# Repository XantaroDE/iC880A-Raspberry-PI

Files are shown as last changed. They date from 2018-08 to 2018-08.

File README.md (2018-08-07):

# Raspberry PI + IMST iC880A Gateway Shield

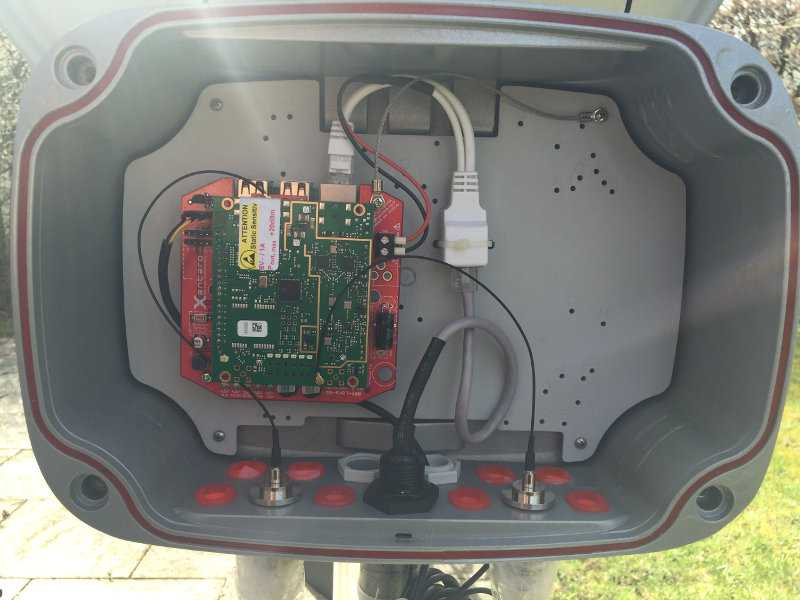
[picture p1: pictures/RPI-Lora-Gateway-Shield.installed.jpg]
Installed
   

Based on the idea of [ch2i][1], but complete rework.

This PCB is used to connect Raspberry PI and ISMT [iC880A][2] LoraWan concentrator Gateway (SPI version) togehter and to be able to put the whole thing into a outdoor enclosure. Power can be supplied via passive or active PoE adapters.

:warning: **Use at your own risk, always check your layout before manufacturing!**

## Features

 - highvoltage power regulator for passive PoE -48V usage based on LM2576
 - optional use DC/DC module for active PoE adapters with +12V output
 - BME280 header for temperature & humidity measurement within the housing, optional BMP280
 - DS18S20 Header for outside & inside/case sensor
 - added GPS module for time & PPS sync
 - optional +3V3 -> +5V TTL serial converter, could be used for other sensors like [SDS011][3] dust particle sensor 
 - LC filters on power supply rails
 - LED for GPS PPS and signal routed to GPIO25
 - DS1307 RTC hardware clock for Raspberry + Battery 

## Schematic

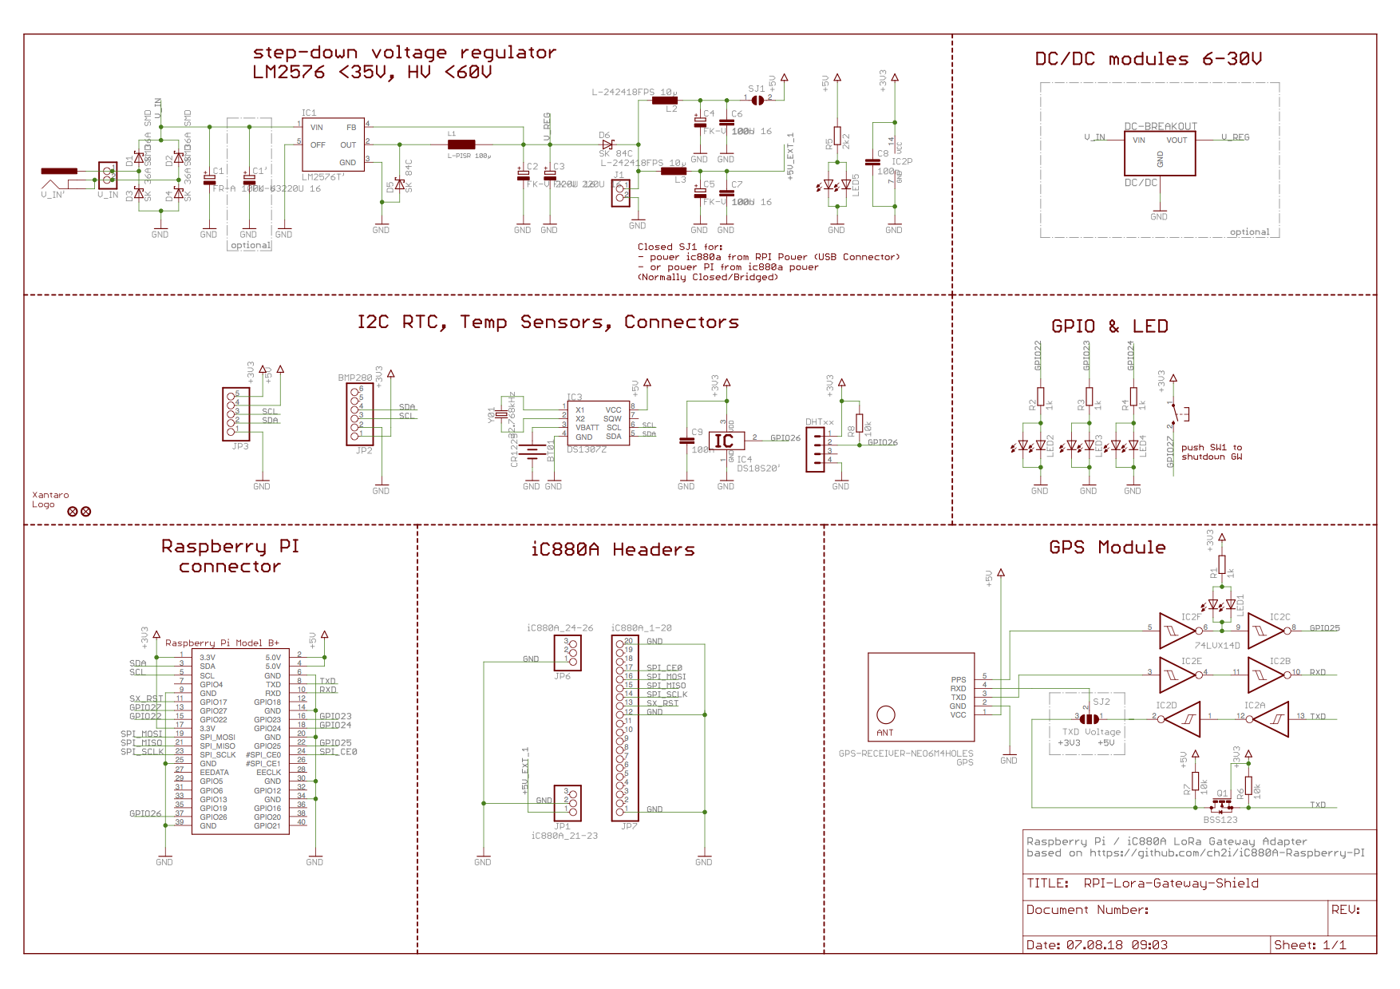
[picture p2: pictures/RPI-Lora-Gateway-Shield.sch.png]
schematic
<br>
[PDF download](https://raw.githubusercontent.com/XantaroDE/iC880A-Raspberry-PI/master/pictures/RPI-Lora-Gateway-Shield.sch.pdf)

## Board

**Top side**

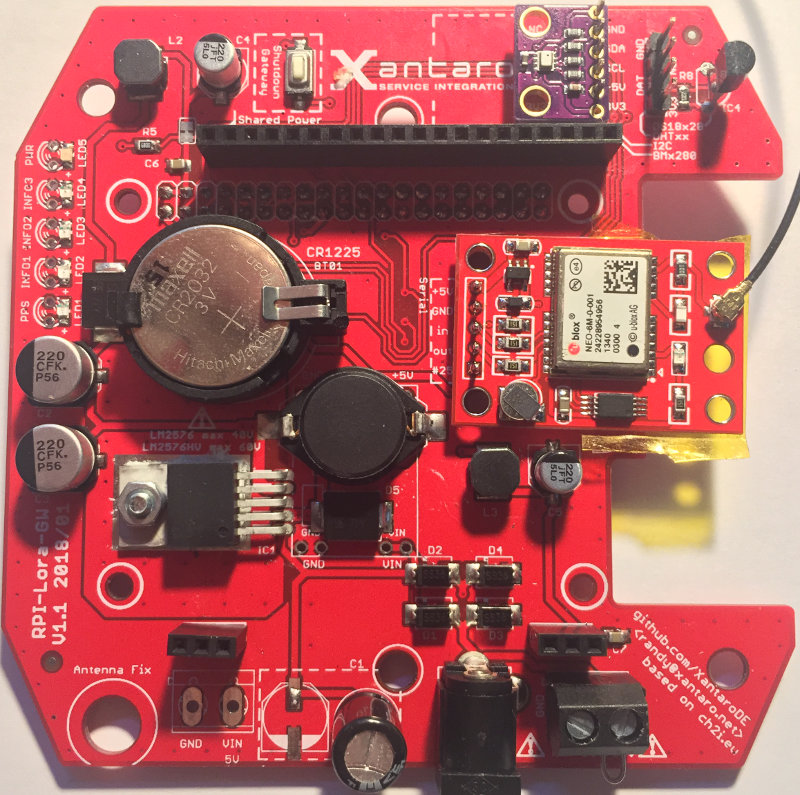
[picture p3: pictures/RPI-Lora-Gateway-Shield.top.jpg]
PCB TOP
    

**Bottom side**

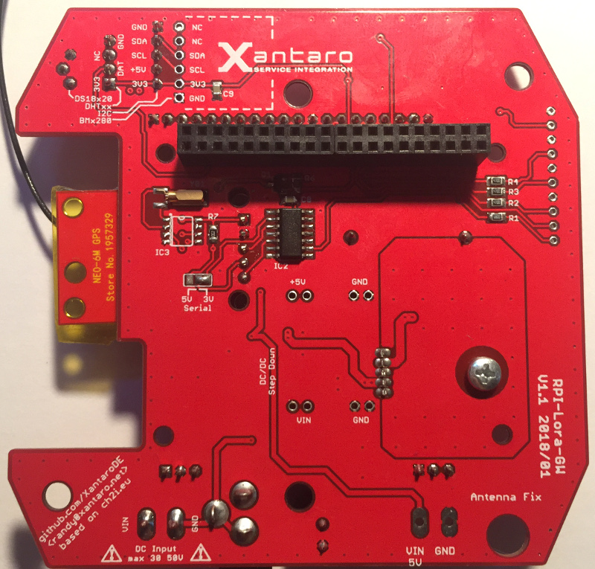
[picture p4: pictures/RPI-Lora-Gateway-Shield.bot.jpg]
PCB BOT
    

You can order the PCB of this board at [elecrow][4] with the supplied gerbers.

## License

   

This work is licensed under a [Creative Commons Attribution-NonCommercial 4.0 International License](http://creativecommons.org/licenses/by-nc/4.0/)    
If you want to do commercial stuff with this project, please contact [Xantaro Deutschland GmbH](https://www.xantaro.net) so we can organize an simple agreement.

[1]: https://github.com/ch2i/iC880A-Raspberry-PI/
[2]: http://webshop.imst.de/ic880a-spi-lorawan-concentrator-868mhz.html
[3]: https://luftdaten.info/
[4]: https://www.elecrow.com/pcb-manufacturing.html

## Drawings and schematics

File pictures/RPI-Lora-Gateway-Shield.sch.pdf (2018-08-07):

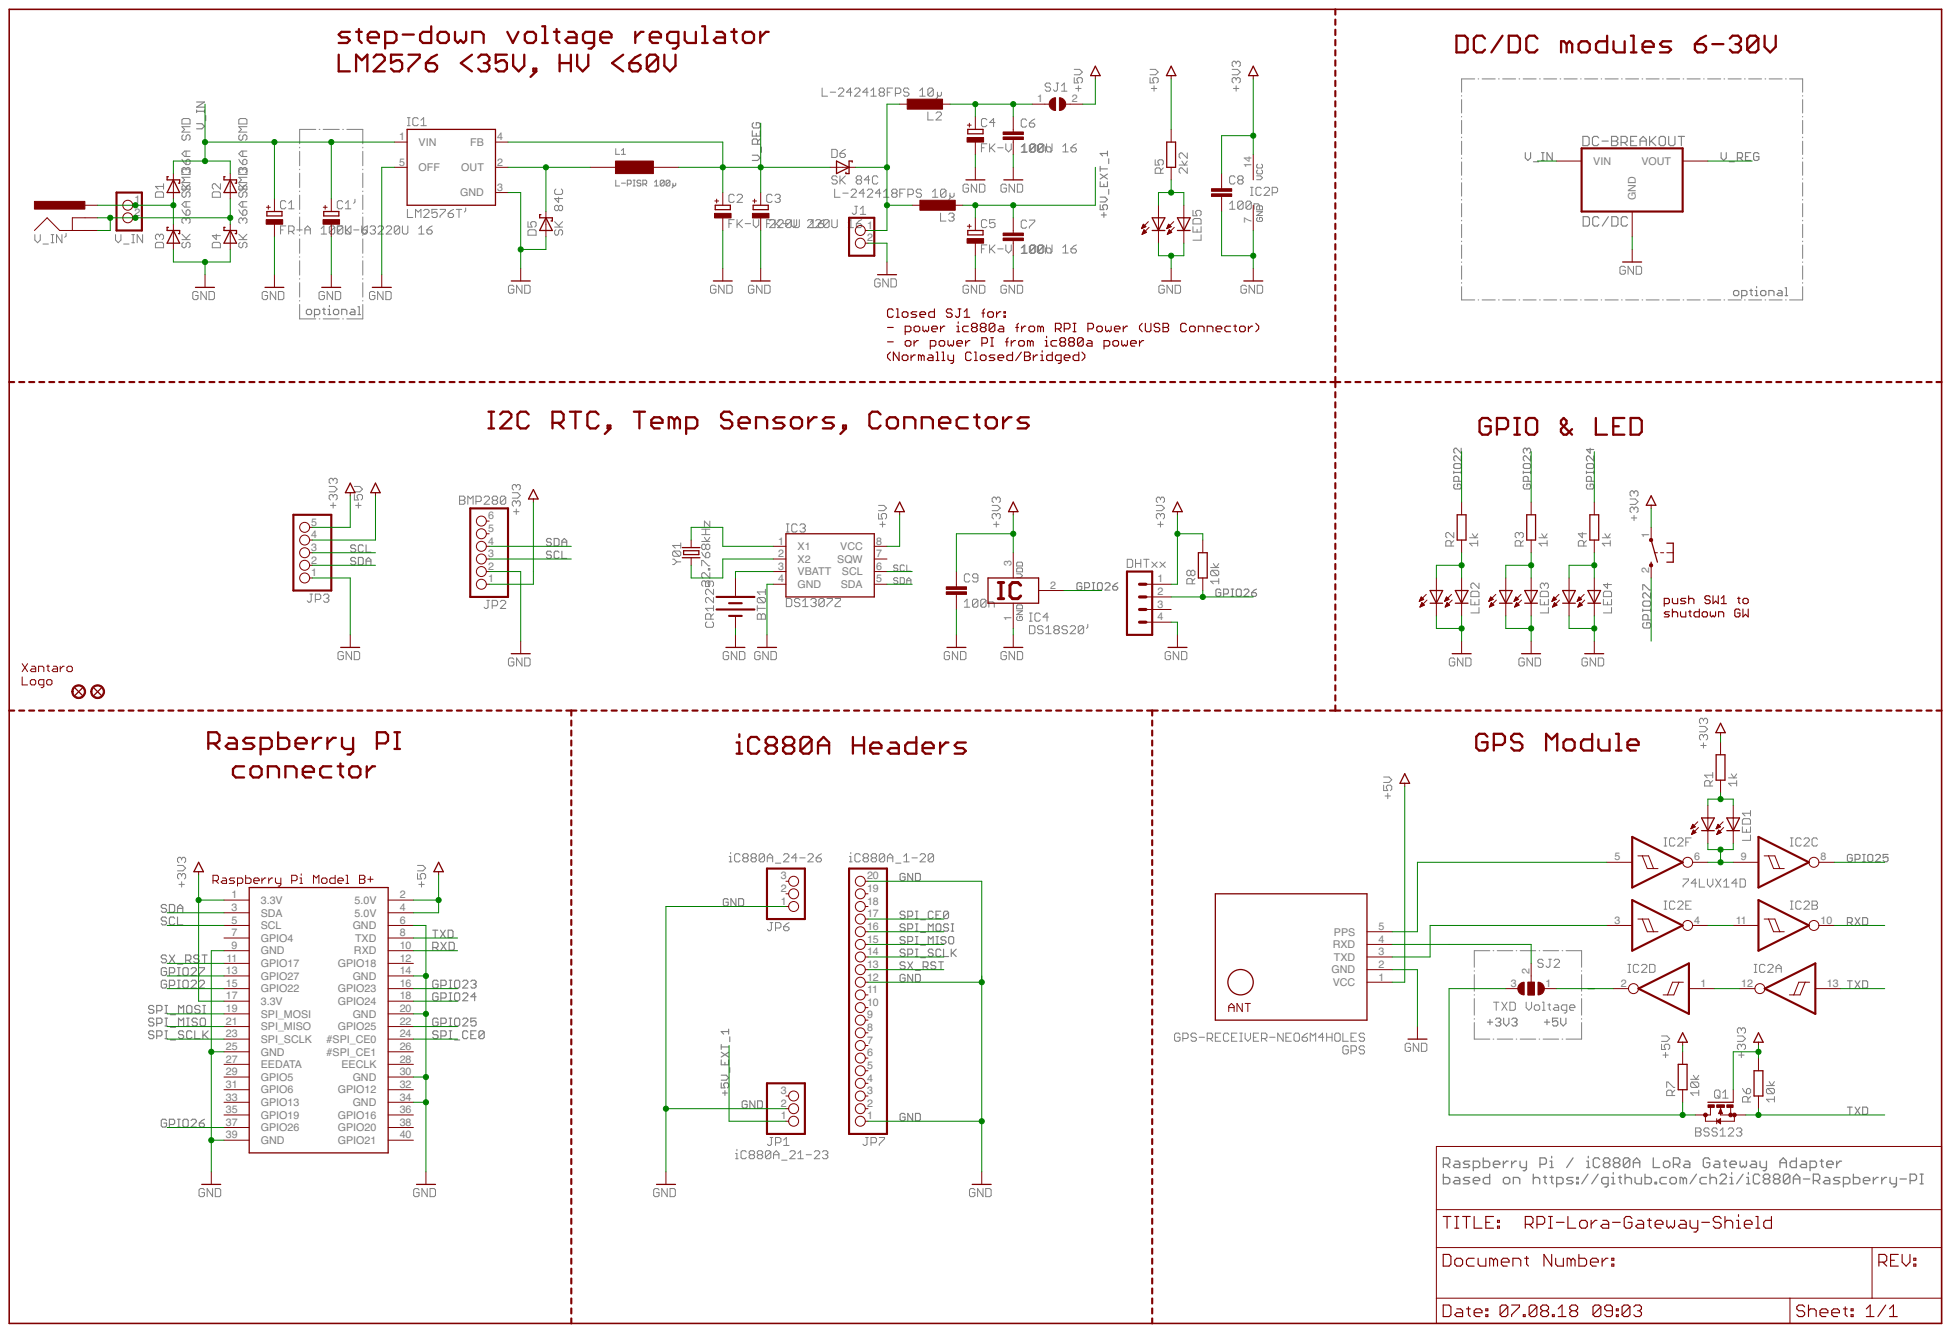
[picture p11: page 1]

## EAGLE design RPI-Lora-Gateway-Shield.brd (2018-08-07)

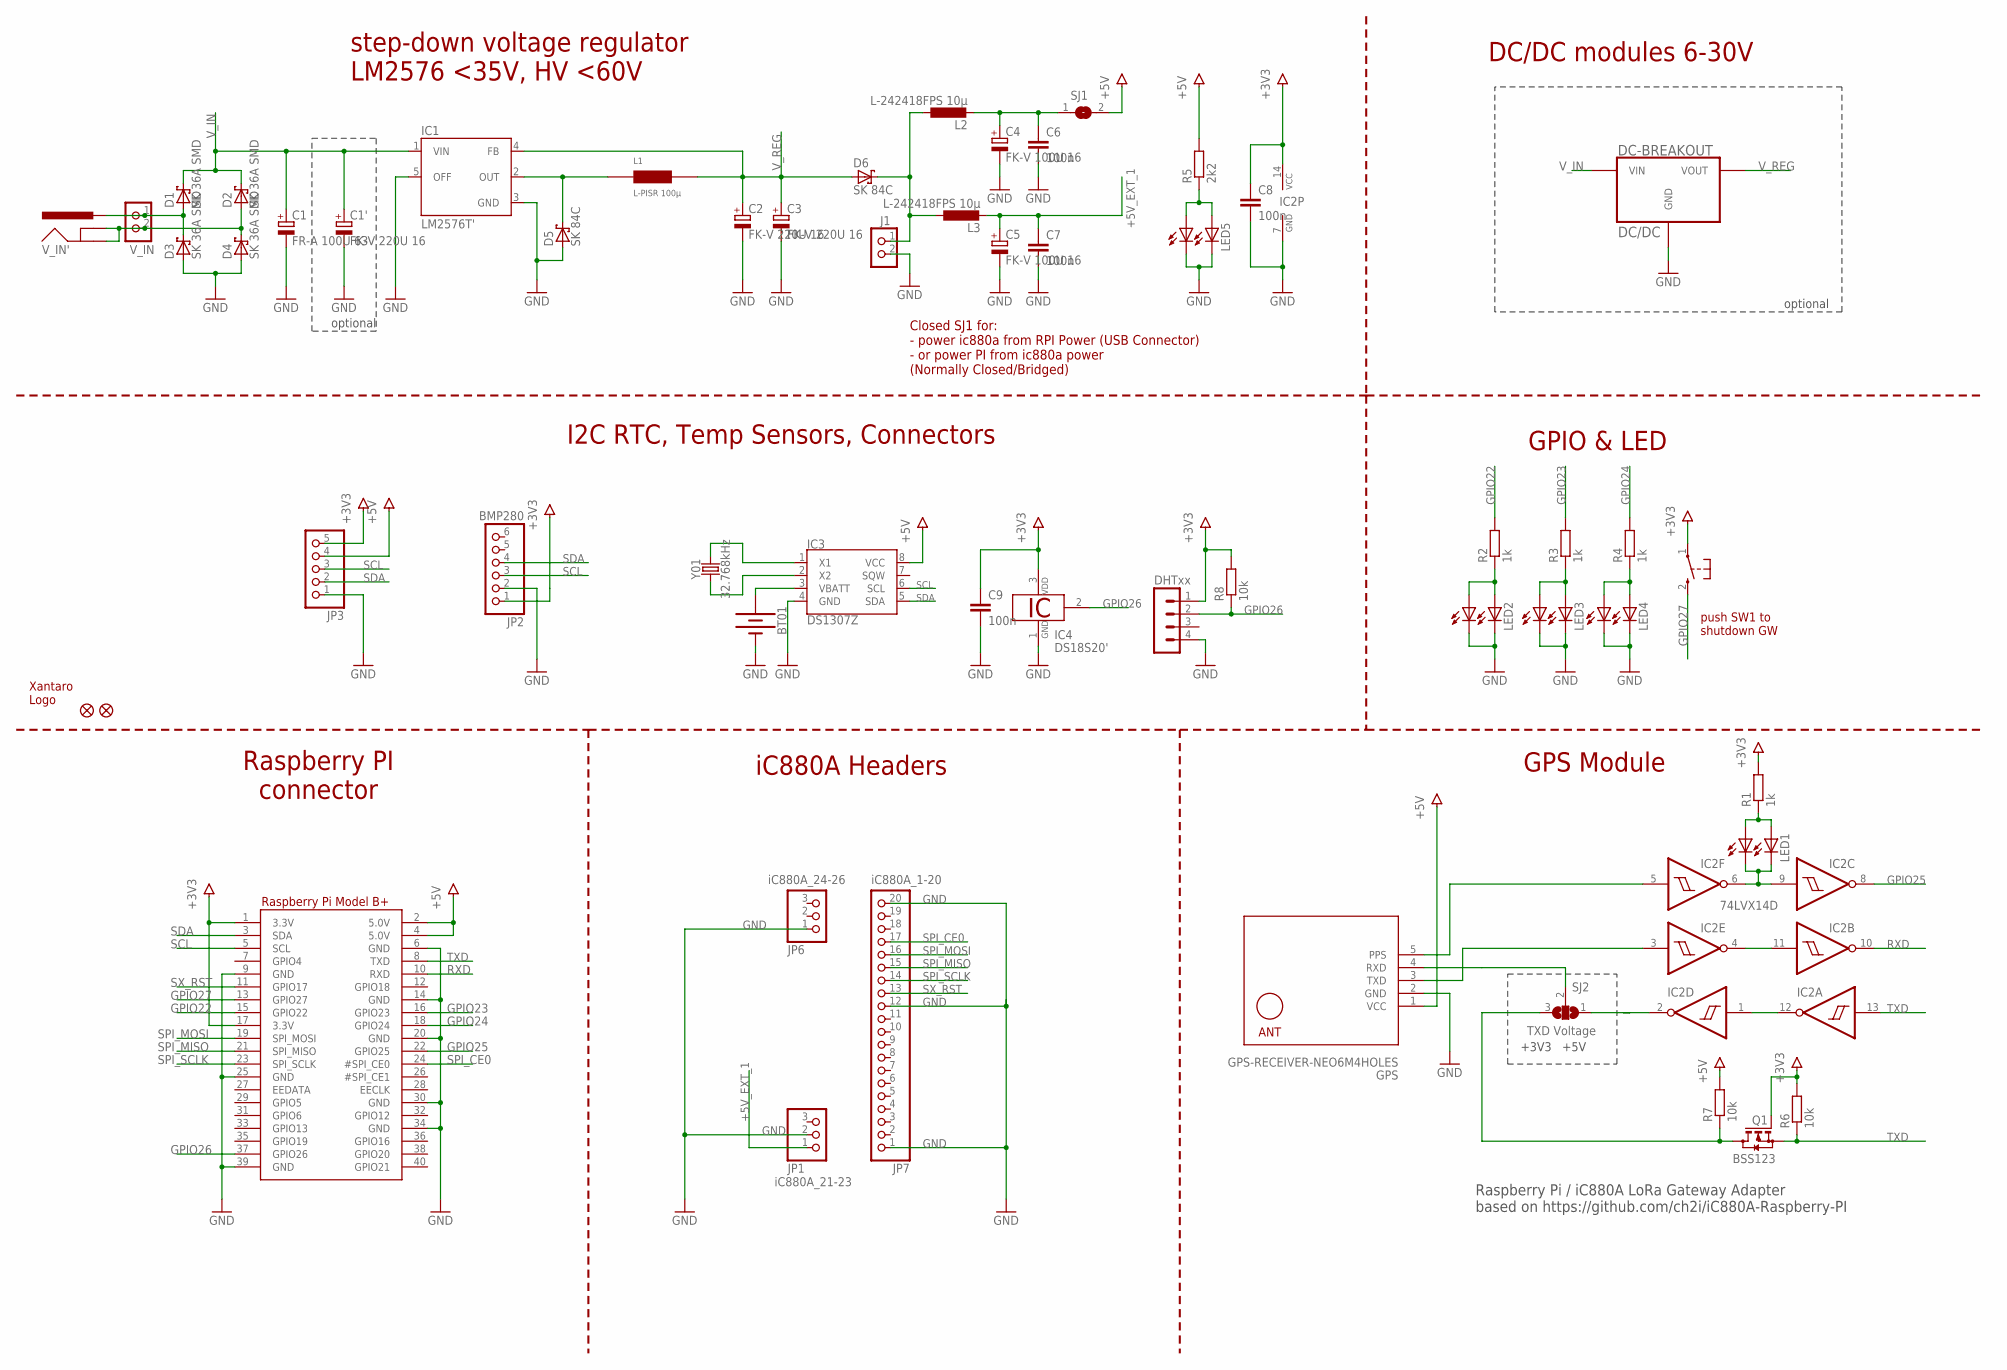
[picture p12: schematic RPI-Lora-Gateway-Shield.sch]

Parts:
BT01: BATTERY-12MM_PTH; BATTCON_12MM_PTH
C1: FR-A 100U 63; E3,5-8
C1', C2, C3: FK-V 220U 16; PANASONIC_E
C4, C5: FK-V 100U 16; PANASONIC_D
C6, C7, C8, C9: 100n; C0805
D1, D2, D3, D4: SK 36A SMD; SMB
D5, D6: SK 84C; SMC
DC/DC: DC-BREAKOUT
FID2, FID3: FIDUCIAL""; FIDUCIAL_1MM
GPS: GPS-RECEIVER-NEO6M4HOLES; GPS-RECEIVER-NEO6M_4HOLES
IC1: LM2576T'; TO220-5_90
IC2: 74LVX14D; SO14
IC3: DS1307Z; SO08-0.15
IC4: DS18S20'; TO92-2
J1: +5V_IN; TERMINAL_BLOCK_2P_5
J5: DHTxx; 1X04_NO_LOCK
JP1: iC880A_21-23; 1X03
JP2: BMP280; 1X06
JP3: PINHD-1X5; 1X05
JP6: iC880A_24-26; 1X03
JP7: iC880A_1-20; 1X20
L1: L-PISR 100µ; PISR
L2, L3: L-242418FPS 10µ; L5650M
LED1, LED2, LED3, LED4, LED5: LEDCHIPLED_0805; CHIPLED_0805
LED1', LED2', LED3', LED4', LED5': LED3MM
Q1: BSS123; SOT23
R1, R2, R3, R4: 1k; R0805
R5: 2k2; R0805
R6, R7, R8: 10k; R0805
RPI1: RASPBERRYPI_BPLUS_IDC; 2X20
SJ1: SJCLOSED; SJ_CLOSED
SJ2: TXD Voltage; SJ_2
SW1': RESET; KSS-2EG4430
U$4: XAN_LOGO_FULL_SILK_L; XAN_FULL_SILK_L
V_IN: V_IN; TERMINAL_BLOCK_2P_5
V_IN': POWER_JACKPTH; POWER_JACK_PTH
Y01: 32.768kHz; CRYSTAL-SMD-2X6-CYL

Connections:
+3V3: C8.1, C9.1, IC2.14 (VCC), IC4.3 (VDD), J5.1, JP2.1, JP3.5, Q1.1 (G), R1.2, R6.2, R8.2, RPI1.1 (3.3V), RPI1.17 (3.3V), SW1'.1
+5V: GPS.1 (VCC), IC3.8 (VCC), JP3.4, R5.2, R7.2, RPI1.2 (5.0V), RPI1.4 (5.0V), SJ1.2
+5V_EXT_1: C5.+, C7.1, JP1.1, L3.2
+5V_EXT_2: C4.+, C6.1, L2.2, SJ1.1
GND: BT01.2 (-), C1.-, C1'.-, C2.-, C3.-, C4.-, C5.-, C6.2, C7.2, C8.2, C9.2, D3.A, D4.A, D5.A, DC/DC.GND-1 (GND), DC/DC.GND-2 (GND), DC/DC.GND-3 (GND), DC/DC.GND-4 (GND), GPS.2 (GND), IC1.3 (GND), IC1.5 (OFF), IC2.7 (GND), IC3.4 (GND), IC4.1 (GND), J1.2, J5.4, JP1.2, JP2.2, JP3.1, JP6.1, JP7.1, JP7.12, JP7.20, LED2.C, LED2'.K (C), LED3.C, LED3'.K (C), LED4.C, LED4'.K (C), LED5.C, LED5'.K (C), RPI1.6 (GND), RPI1.9 (GND), RPI1.14 (GND), RPI1.20 (GND), RPI1.25 (GND), RPI1.30 (GND), RPI1.34 (GND), RPI1.39 (GND)
GPIO22: R2.2, RPI1.15 (GPIO22)
GPIO23: R3.2, RPI1.16 (GPIO23)
GPIO24: R4.2, RPI1.18 (GPIO24)
GPIO25: IC2.8 (O), RPI1.22 (GPIO25)
GPIO26: IC4.2 (1W), J5.2, R8.1, RPI1.37 (GPIO26)
GPIO27: RPI1.13 (GPIO27), SW1'.2 (S)
unnamed: D1.A, D3.C, V_IN.1, V_IN'.PWR
unnamed: LED1.A, LED1'.A, R1.1
unnamed: IC2.1 (I), IC2.12 (O)
unnamed: D6.C, J1.1, L2.1, L3.1
unnamed: D2.A, D4.C, V_IN.2, V_IN'.GND, V_IN'.GNDBREAK
unnamed: GPS.5 (PPS), IC2.5 (I)
unnamed: IC2.6 (O), IC2.9 (I), LED1.C, LED1'.K (C)
unnamed: GPS.3 (TXD), IC2.3 (I)
unnamed: IC2.4 (O), IC2.11 (I)
unnamed: GPS.4 (RXD), SJ2.2
unnamed: IC2.2 (O), SJ2.1
unnamed: D5.C, IC1.2 (OUT), L1.1
unnamed: BT01.1 (+), IC3.3 (VBATT)
unnamed: IC3.2 (X2), Y01.X1 (1)
unnamed: IC3.1 (X1), Y01.X2 (2)
unnamed: LED5.A, LED5'.A, R5.1
unnamed: LED3.A, LED3'.A, R3.1
unnamed: LED4.A, LED4'.A, R4.1
unnamed: Q1.3 (D), R7.1, SJ2.3
unnamed: LED2.A, LED2'.A, R2.1
RXD: IC2.10 (O), RPI1.10 (RXD)
SCL: IC3.6 (SCL), JP2.3, JP3.3, RPI1.5 (SCL)
SDA: IC3.5 (SDA), JP2.4, JP3.2, RPI1.3 (SDA)
SPI_CE0: JP7.17, RPI1.24 (#SPI_CE0)
SPI_MISO: JP7.15, RPI1.21 (SPI_MISO)
SPI_MOSI: JP7.16, RPI1.19 (SPI_MOSI)
SPI_SCLK: JP7.14, RPI1.23 (SPI_SCLK)
SX_RST: JP7.13, RPI1.11 (GPIO17)
TXD: IC2.13 (I), Q1.2 (S), R6.1, RPI1.8 (TXD)
V_IN: C1.+, C1'.+, D1.C, D2.C, DC/DC.VIN-1 (VIN), DC/DC.VIN-2 (VIN), IC1.1 (VIN)
V_REG: C2.+, C3.+, D6.A, DC/DC.VOUT-1 (VOUT), DC/DC.VOUT-2 (VOUT), IC1.4 (FB), L1.2

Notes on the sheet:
iC880A Headers
GPS Module
Raspberry PI connector
GPIO & LED
I2C RTC, Temp Sensors, Connectors
Closed SJ1 for: - power ic880a from RPI Power (USB Connector) - or power PI from ic880a power (Normally Closed/Bridged)
push SW1 to shutdown GW
step-down voltage regulator LM2576 <35V, HV <60V
DC/DC modules 6-30V
optional
+3V3 +5V
Raspberry Pi / iC880A LoRa Gateway Adapter based on https://github.com/ch2i/iC880A-Raspberry-PI

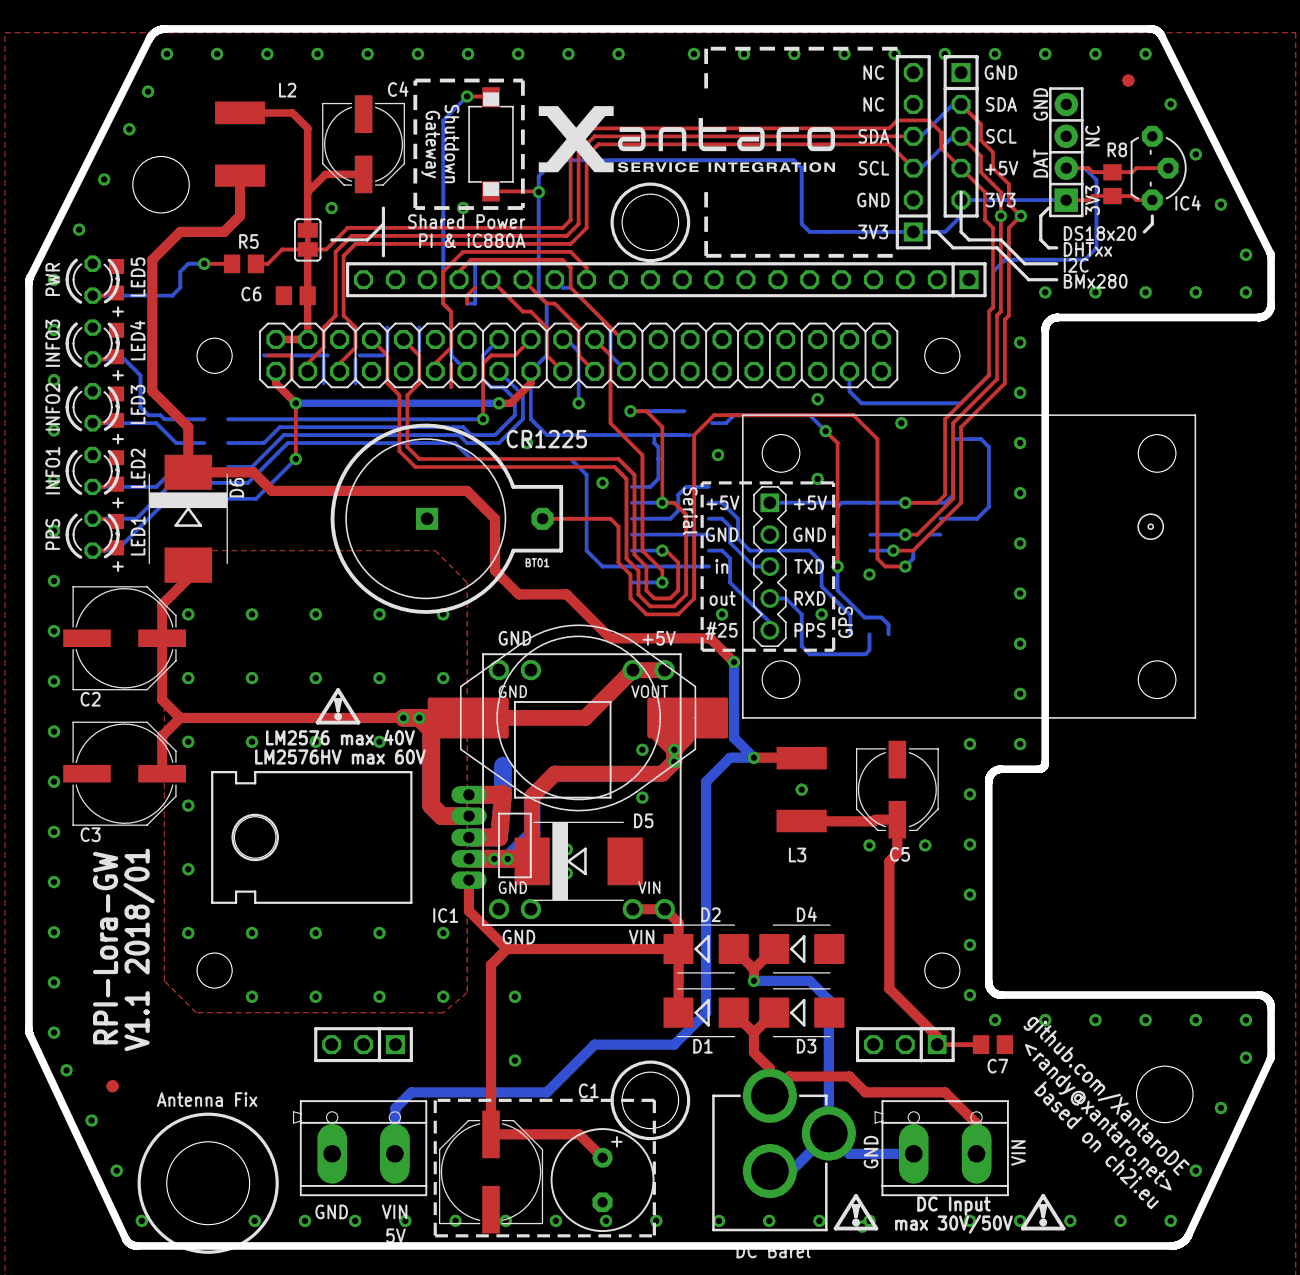
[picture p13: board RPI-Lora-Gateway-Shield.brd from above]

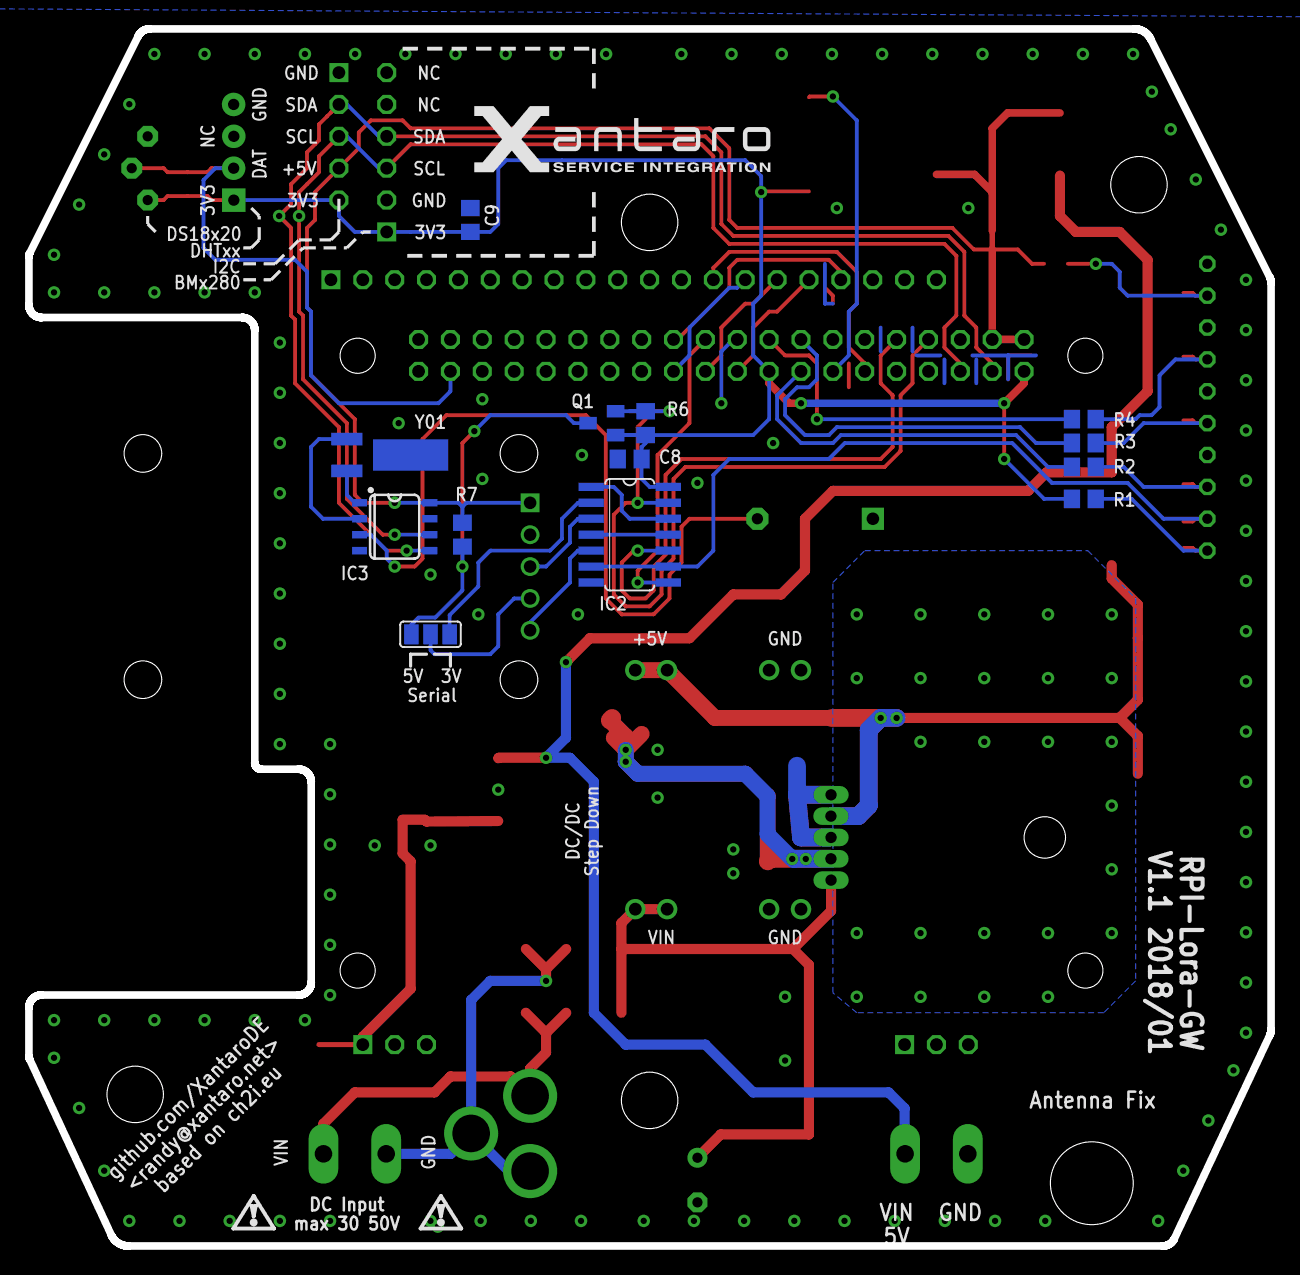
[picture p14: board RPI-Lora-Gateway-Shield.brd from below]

Board: 2 copper layers, 99.0 x 97.0 mm, 63 parts (14 on the bottom side), 42 nets.

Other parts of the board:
U$5: XAN_LOGO_FULL_SILK_L; XAN_FULL_SILK_L

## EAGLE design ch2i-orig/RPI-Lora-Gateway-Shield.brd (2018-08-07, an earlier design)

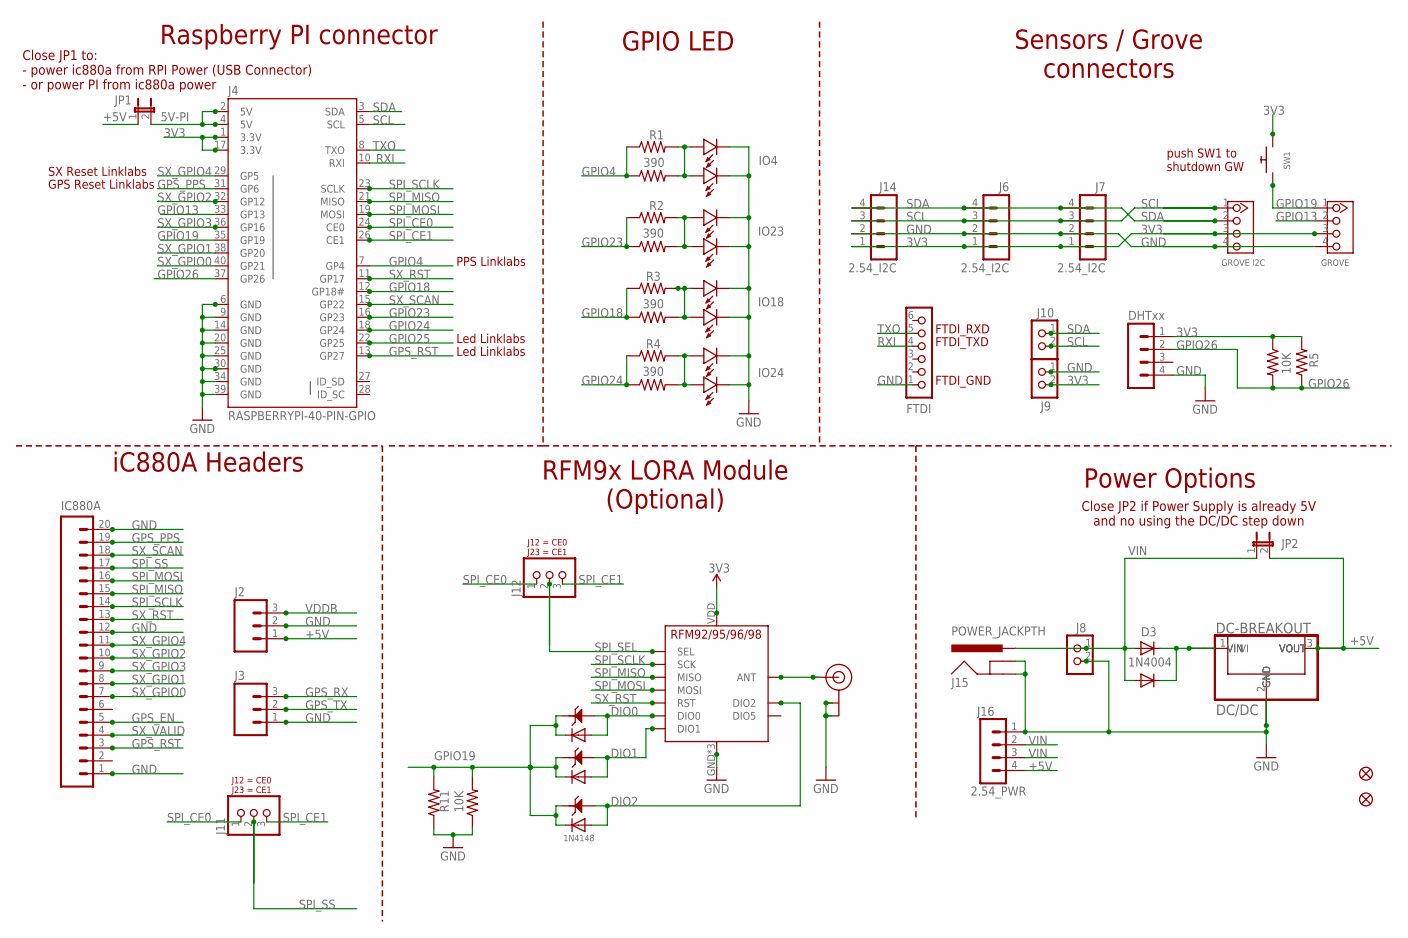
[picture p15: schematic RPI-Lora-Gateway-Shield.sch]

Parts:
D0, D1, D2: 1N4148; SOD123-2.7X1.6
D3: 1N4004; DO41-10
D4: 1N4007; DO-214AC
D5: 1N4148; DO-1N4148
D6, D7: DIODEDO-1N4148; DO-1N4148
DC/DC: DC-BREAKOUT
FID2, FID3: FIDUCIAL""; FIDUCIAL_1MM
FTDI: CON_HEADER_1X06-PTH; M1X6
IC880A: M20LOCK; 1X20_LOCK
J1: GROVE; HW4-2.0
J2, J3: M03LOCK; 1X03_LOCK
J4: RASPBERRYPI-40-PIN-GPIO; 2X20-SHROUDED
J5: DHTxx; 1X04_NO_LOCK
J6, J7, J14: 2.54_I2C; 1X04_NO_LOCK
J8, J9, J10: CON_TERMINAL_BLOCK_02-5MM; TERMINAL_BLOCK_2P_5
J11, J12: JUMPER_1X30805; JP3_0805
J13: GROVE I2C; HW4-2.0
J15: POWER_JACKPTH; POWER_JACK_PTH
J16: 2.54_PWR; 1X04_NO_LOCK
JP1, JP2: JUMPER2
LED1, LED2, LED3, LED4: LED0805; 0805-LED
R1, R2, R3, R4: 390; AXIAL-0.4
R5, R11: 10K; AXIAL-0.4
R6, R7, R8, R9, R10, R12: RESISTOR0805-RES; 0805-RES
SW1: SWITCH_PUSHBUTTONEVQ-PE; TACT_PANA-EVQ
U$2: RFM95
U$3: ANTENNA-UFL; UFL_PAD
U$4: IO4; LED3MM
U$5: IO23; LED3MM
U$6: IO18; LED3MM
U$7: IO24; LED3MM
U$8: DC-BREAKOUTFIXED; DC-DC-FIXED
U$11: OKI-78SR; OKI-78SRH

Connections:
3V3: J1.3, J4.1 (3.3V), J4.17 (3.3V), J5.1, J6.1, J7.1, J9.2, J13.3, J14.1, R5.P$1 (1), R10.2, SW1.P$2, U$2.VDD (VCC)
5V-PI: J4.2 (5V), J4.4 (5V), JP1.2
+5V: DC/DC.VOUT-1 (VOUT), DC/DC.VOUT-2 (VOUT), J2.1, J16.4, JP1.1, JP2.2, U$8.VOUT-1 (VOUT), U$8.VOUT-2 (VOUT), U$11.3 (VO)
DIO0: D0.1, D6.A, U$2.DIO0
DIO1: D1.1, D7.A, U$2.DIO1
DIO2: D2.1, D5.A, U$2.DIO2
GND: DC/DC.GND-1 (GND), DC/DC.GND-2 (GND), DC/DC.GND-3 (GND), DC/DC.GND-4 (GND), FTDI.1, IC880A.1, IC880A.12, IC880A.20, J1.4, J2.2, J3.1, J4.6 (GND), J4.9 (GND), J4.14 (GND), J4.20 (GND), J4.25 (GND), J4.30 (GND), J4.34 (GND), J4.39 (GND), J5.4, J6.2, J7.2, J8.2, J9.1, J13.4, J14.2, J15.GND, J15.GNDBREAK, J16.1, LED1.MINUS, LED2.MINUS, LED3.MINUS, LED4.MINUS, R11.P$1 (1), R12.1, U$2.GND, U$2.GND1 (GND), U$2.GND2 (GND), U$3.GND1 (GND), U$3.GND2 (GND), U$4.MINUS, U$5.MINUS, U$6.MINUS, U$7.MINUS, U$8.GND-1 (GND), U$8.GND-2 (GND), U$8.GND-3 (GND), U$8.GND-4 (GND), U$11.2 (GND)
GPIO4: J4.7 (GP4), R1.P$1 (1), R6.1
GPIO13: J1.2, J4.33 (GP13)
GPIO18: J4.12 (GP18#), R3.P$1 (1), R8.1
GPIO19: D0.2, D1.2, D2.2, D5.C, D6.C, D7.C, J1.1, J4.35 (GP19), R11.P$2 (2), R12.2, SW1.P$1
GPIO23: J4.16 (GP23), R2.P$1 (1), R7.1
GPIO24: J4.18 (GP24), R4.P$1 (1), R9.1
GPIO25: J4.22 (GP25)
GPIO26: J4.37 (GP26), J5.2, R5.P$2 (2), R10.1
GPS_EN: IC880A.5
GPS_PPS: IC880A.19, J4.31 (GP6)
GPS_RST: IC880A.3, J4.13 (GP27)
GPS_RX: J3.3
GPS_TX: J3.2
unnamed: D3.C, D4.1 (C), DC/DC.VIN-1 (VIN), DC/DC.VIN-2 (VIN), U$8.VIN-1 (VIN), U$8.VIN-2 (VIN), U$11.1 (VI)
unnamed: LED4.PLUS, R4.P$2 (2), R9.2, U$7.PLUS
unnamed: LED1.PLUS, R1.P$2 (2), R6.2, U$4.PLUS
unnamed: LED2.PLUS, R2.P$2 (2), R7.2, U$5.PLUS
unnamed: LED3.PLUS, R3.P$2 (2), R8.2, U$6.PLUS
unnamed: U$2.ANT, U$3.ANT1 (SIGNAL), U$3.ANT2 (SIGNAL)
RXI: FTDI.4, J4.10 (RXI)
SCL: J4.5 (SCL), J6.3, J7.3, J10.2, J13.1, J14.3
SDA: J4.3 (SDA), J6.4, J7.4, J10.1, J13.2, J14.4
SPI_CE0: J4.24 (CE0), J11.1, J12.1
SPI_CE1: J4.26 (CE1), J11.3, J12.3
SPI_MISO: IC880A.15, J4.21 (MISO), U$2.MISO
SPI_MOSI: IC880A.16, J4.19 (MOSI), U$2.MOSI
SPI_SCLK: IC880A.14, J4.23 (SCLK), U$2.SCK
SPI_SEL: J12.2, U$2.NSS (SEL)
SPI_SS: IC880A.17, J11.2
SX_GPIO0: IC880A.7, J4.40 (GP21)
SX_GPIO1: IC880A.8, J4.38 (GP20)
SX_GPIO2: IC880A.10, J4.32 (GP12)
SX_GPIO3: IC880A.9, J4.36 (GP16)
SX_GPIO4: IC880A.11, J4.29 (GP5)
SX_RST: IC880A.13, J4.11 (GP17), U$2.RST
SX_SCAN: IC880A.18, J4.15 (GP22)
SX_VALID: IC880A.4
TXO: FTDI.5, J4.8 (TXO)
VDDB: J2.3
VIN: D3.A, D4.2 (A), J8.1, J15.PWR, J16.2, J16.3, JP2.1

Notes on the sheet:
PPS Linklabs
SX Reset Linklabs
GPS Reset Linklabs
Led Linklabs
iC880A Headers
RFM9x LORA Module (Optional)
Power Options
Raspberry PI connector
GPIO LED
Sensors / Grove connectors
Close JP2 if Power Supply is already 5V and no using the DC/DC step down
Close JP1 to: - power ic880a from RPI Power (USB Connector) - or power PI from ic880a power
FTDI_RXD
FTDI_TXD
FTDI_GND
push SW1 to shutdown GW

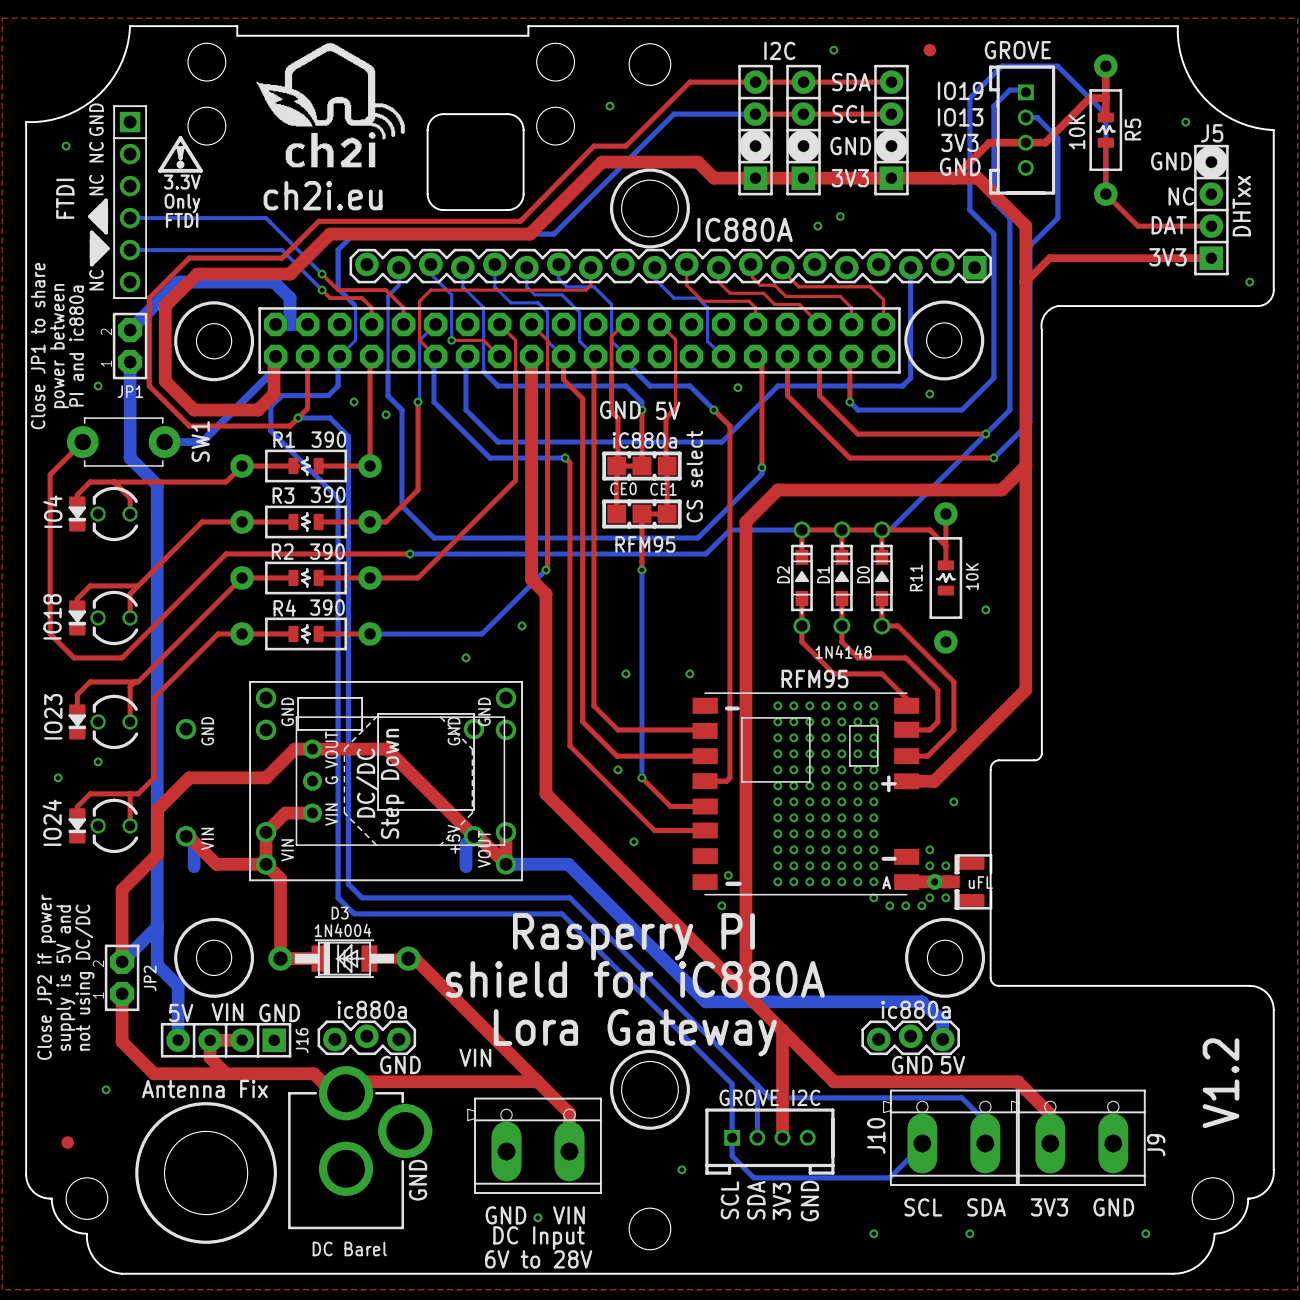
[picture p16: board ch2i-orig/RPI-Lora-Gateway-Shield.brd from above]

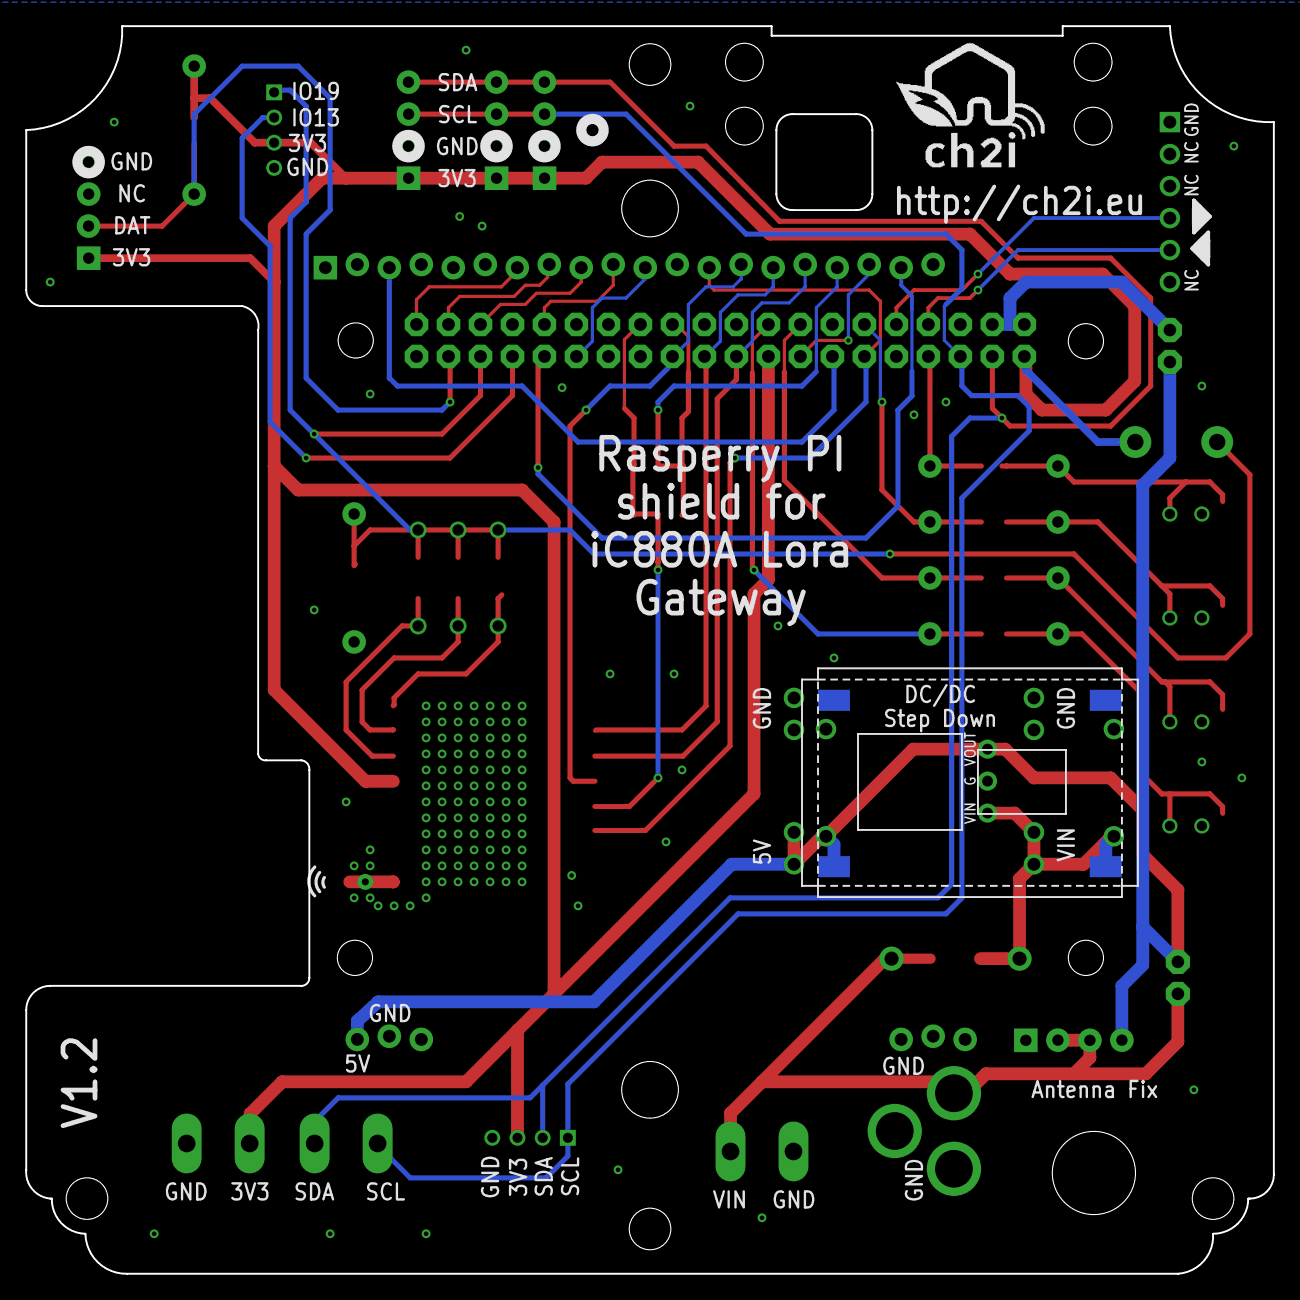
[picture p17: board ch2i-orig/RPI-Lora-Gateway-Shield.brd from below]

Board: 2 copper layers, 99.1 x 99.1 mm, 62 parts (2 on the bottom side), 41 nets.

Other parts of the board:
H1, H2, H3, H4: STAND-OFF
U$1, U$9: LOGO_CH2I_110MM

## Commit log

2018-08-07 moved original files into ch2i-orig/
    [RPI-Lora-Gateway-Shield.GBL, RPI-Lora-Gateway-Shield.GBO, RPI-Lora-Gateway-Shield.GBP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]
2018-08-07 push own version, schematics, gerber files...
    [RPI-Lora-Gateway-Shield.GBL, RPI-Lora-Gateway-Shield.GBO, RPI-Lora-Gateway-Shield.GBP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]

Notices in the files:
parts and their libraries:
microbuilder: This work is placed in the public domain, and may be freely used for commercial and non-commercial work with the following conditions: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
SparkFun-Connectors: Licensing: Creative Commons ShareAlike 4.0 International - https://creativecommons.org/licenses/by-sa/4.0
